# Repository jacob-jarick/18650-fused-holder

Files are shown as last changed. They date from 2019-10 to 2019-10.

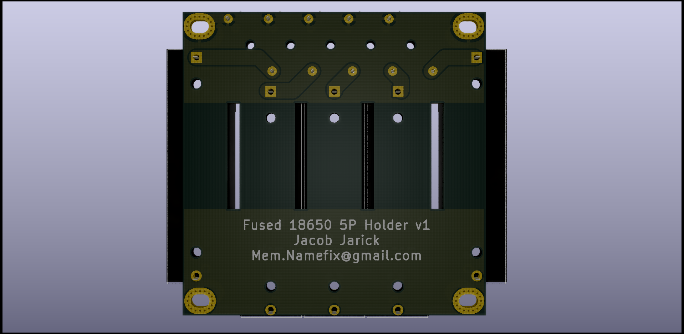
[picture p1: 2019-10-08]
18650 holder back.png

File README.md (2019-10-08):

# 5p 18650 Holder

Designed with the goal of a long life time of usage with very easy maintenance and servicing.

# Features
- 10x10cm PCB (cheap).
- per cell fusing using 5x20mm Glass Fuses
- blown fuse indicator LEDs
- m4 mounting pads.

I will be using these to build my power walls.

## BoM Est

$4.50 aud

# Notes

## Bus Bar

I plan to use copper pipe 1/2 inch.

## Attachment to bus bar

copper rivets is the cheapeast option, best option is nutserts and m4 bolts.

## Connecting multiple boards.

using a 2p 18650 case you can join two boards together by placing the 2p case over the end cell spots (eg cell 4 on board 1 and cell 1 on board 2).

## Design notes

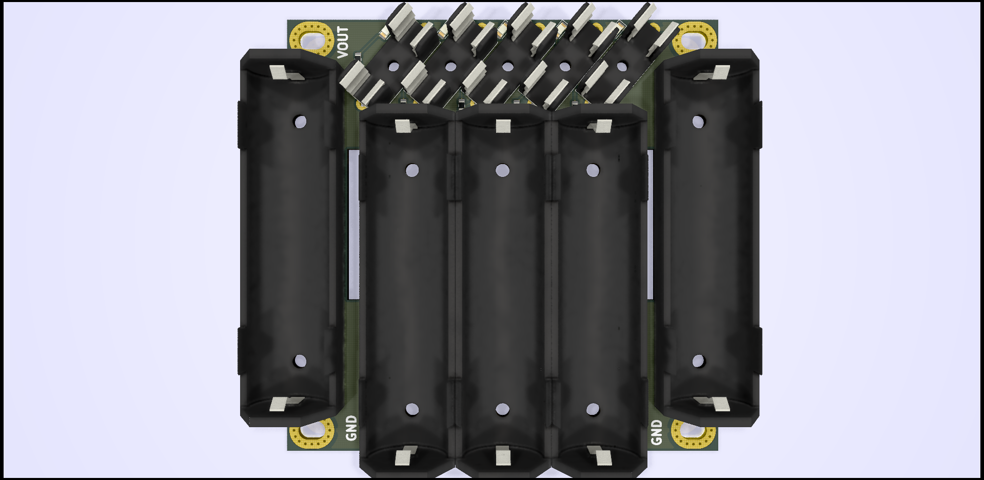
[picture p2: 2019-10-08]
18650 holder front.png

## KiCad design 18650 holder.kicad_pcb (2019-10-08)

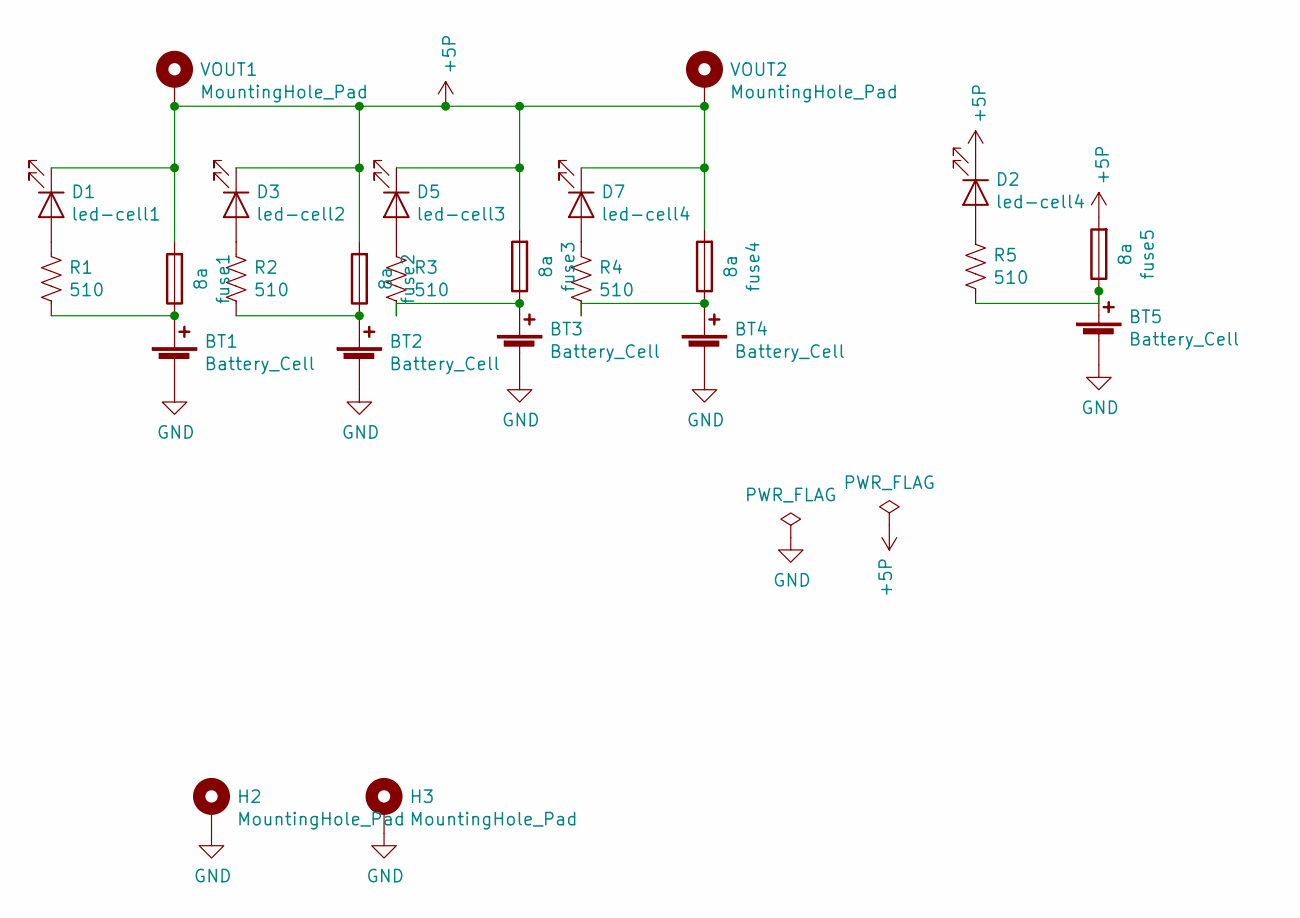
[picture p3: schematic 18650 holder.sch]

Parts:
BT1, BT2, BT3, BT4, BT5: Battery_Cell; BatteryHolder_MPD_BH-18650-PC2
D1: led-cell1; LED_1206_3216Metric-witharrow
D2, D7: led-cell4; LED_1206_3216Metric-witharrow
D3: led-cell2; LED_1206_3216Metric-witharrow
D5: led-cell3; LED_1206_3216Metric-witharrow
H2, H3: MountingHole_Pad; MountingHole_4.3x6.2mm_M4_Pad_Via
R1, R2, R3, R4, R5: 510; R_0805_2012Metric_Pad1.15x1.40mm_HandSolder
VOUT1, VOUT2: MountingHole_Pad; MountingHole_4.3x6.2mm_M4_Pad_Via
fuse1, fuse2, fuse3, fuse4, fuse5: 8a; Fuseholder_Cylinder-5x20mm_Schurter_0031_8201_Horizontal_Op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

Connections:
+5P: D1.1 (K), D2.1 (K), D3.1 (K), D5.1 (K), D7.1 (K), VOUT1.1, VOUT2.1, fuse1.2, fuse2.2, fuse3.2, fuse4.2, fuse5.2
GND: BT1.2 (-), BT2.2 (-), BT3.2 (-), BT4.2 (-), BT5.2 (-), H2.1, H3.1
unnamed: BT1.1 (+), R1.2, fuse1.1
unnamed: BT2.1 (+), R2.2, fuse2.1
unnamed: BT3.1 (+), R3.2, fuse3.1
unnamed: BT4.1 (+), R4.2, fuse4.1
unnamed: BT5.1 (+), R5.2, fuse5.1
unnamed: D1.2 (A), R1.1
unnamed: D2.2 (A), R5.1
unnamed: D3.2 (A), R2.1
unnamed: D5.2 (A), R3.1
unnamed: D7.2 (A), R4.1

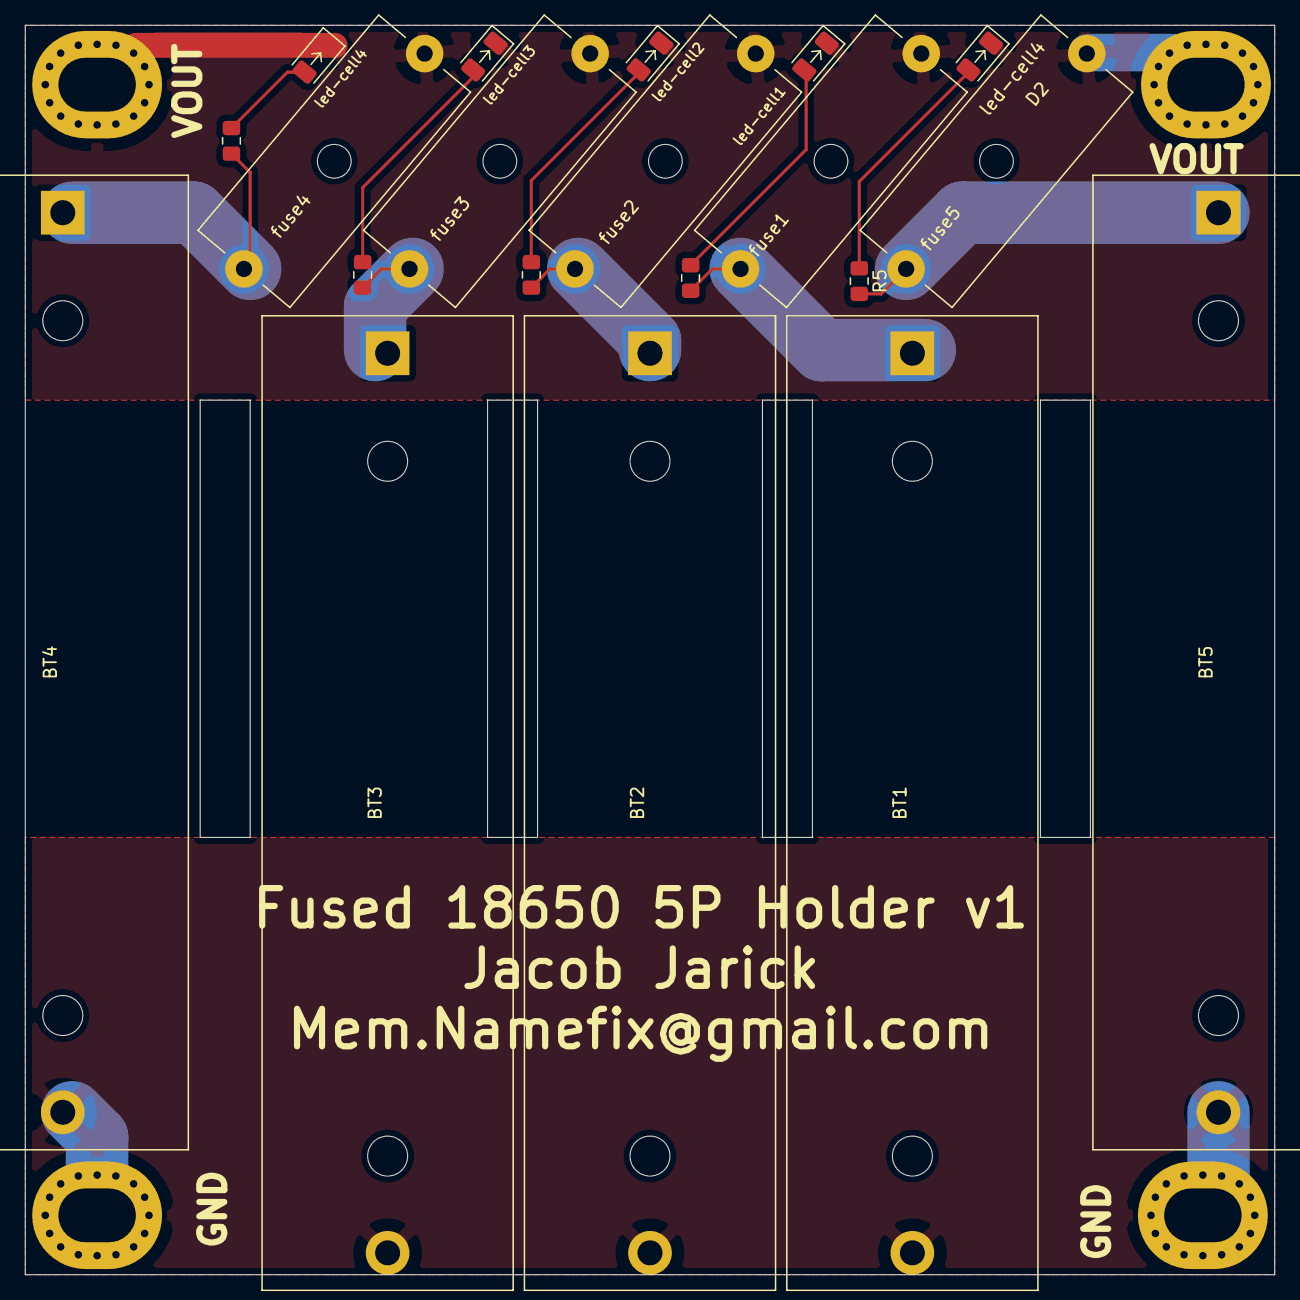
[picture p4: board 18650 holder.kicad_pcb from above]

Board: 2 copper layers, 100.0 x 100.0 mm, 24 parts (0 on the bottom side), 12 nets.
